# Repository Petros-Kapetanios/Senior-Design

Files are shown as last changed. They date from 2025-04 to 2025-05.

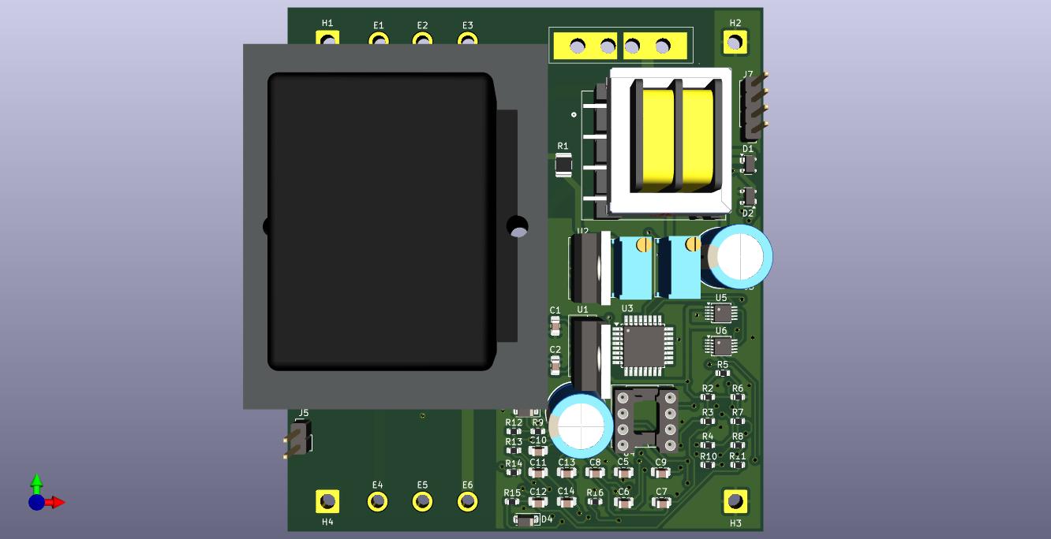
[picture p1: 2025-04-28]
Final_Board-v3C/Final_Board-v3C.jpg

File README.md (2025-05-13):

# Senior‑Design

Zip files of my Gerber files for each PCB I created for my watt‑meter project.

## Order of Creation

1. **Capacitor Test Board**
2. **Current Transformer Test Board**
3. **Voltage Transformer Test Board**
4. **Low Pass‑V1**
5. **Low Pass‑V2**
6. **Final_Board‑Analog‑v1**
7. **Final_Board‑Analog‑v2**
8. **Final_Board‑Analog‑v3**
9. **Final_Board‑v1**
10. **Final_Board‑v2**
11. **Final_Board‑v3‑Triple‑Transformer**
12. **Final_Board‑v3B**
13. **Final_Board‑v3B‑Mark’s Copy**
14. **Final_Board‑v3C**
15. **Final_Board‑v3D**

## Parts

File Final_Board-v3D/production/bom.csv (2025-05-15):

Designator | Footprint | Quantity | Value | LCSC Part #
C1, C4 | CP_Radial_D10.0mm_P5.00mm | 2 | 100 uF
C10, C11, C12, C9 | 0805 | 4 | 1.5 uF
C13, C8 | 0805 | 2 | 10 nF
C14 | 0805 | 1 | 22 nF
C2, C3, C5, C6 | 0805 | 4 | 1 uF
C7 | 0805 | 1 | 20 nF
D1, D2 | SOT-143 | 2 | BAS3007
D3, D4 | D_SOD-123 | 2 | D_Zener
E1, E2, E3, E4, E5, E6 | MountingHole_2.2mm_M2_ISO7380_Pad_TopBottom | 6 | TestPoint_Small
F1 | Fuseholder_Keystone_3555-2 | 1 | Fuse
H1, H2, H3, H4 | SolderWire-2sqmm_1x01_D2mm_OD3.9mm | 4 | Hole
J1, J4 | PinHeader_1x02_P2.54mm_Vertical | 2 | Conn_01x02_Pin
J1-2 | PinHeader_2x03_P2.54mm_Vertical | 1 | Conn_02x03_Odd_Even
J10, J8 | PinHeader_1x01_P2.54mm_Vertical | 2 | Conn_01x01_Pin
J5 | PinHeader_1x04_P2.54mm_Vertical | 1 | Conn_01x04_Pin
J6, J7 | PinSocket_1x02_P2.54mm_Vertical | 2 | Conn_01x02_Socket
J9 | PinSocket_1x04_P2.54mm_Vertical | 1 | Conn_01x04_Socket
R1 | 1210 | 1 | 240 K
R10 | 0603 | 1 | 1 K
R11, R13, R14, R17, R2, R3, R5, R7, R8 | 0603 | 9 | 10 K
R12, R6 | 0603 | 2 | 51.1 K
R15 | 0603 | 1 | 30
R16, R4 | 0603 | 2 | 20 K
R9 | 0603 | 1 | 3 K
RV1 | Potentiometer_Bourns_3296W_Vertical | 1 | 10K Pot
RV2 | Potentiometer_Bourns_3296W_Vertical | 1 | 10 K Pot
T1 | XFMR_VPP12-800 | 1 | VPP12-800
T2 | XFMR_CSE185L | 1 | CSE185L
U1 | TO-220-3_Vertical | 1 | 12 V Regulator
U2 | TO-220-3_Vertical | 1 | 5 V Regulator
U3 | TQFP-32_7x7mm_P0.8mm | 1 | ATmega328PB-A
U4 | DIP-8_W7.62mm_Socket | 1 | LM358
U5, U6 | TSSOP-10_3x3mm_P0.5mm | 2 | ADS1115IDGS

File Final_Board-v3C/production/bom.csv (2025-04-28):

Designator | Footprint | Quantity | Value | LCSC Part #
C1, C2, C5, C6 | 0805 | 4 | 1 uF
C10, C11, C12, C9 | 0805 | 4 | 1.5 uF
C13 | 0805 | 1 | 22 nF
C14, C8 | 0805 | 2 | 10 nF
C3, C4 | CP_Radial_D10.0mm_P5.00mm | 2 | 100 uF
C7 | 0805 | 1 | 20 nF
D1, D2 | SOT-143 | 2 | BAS3007
D3, D4 | D_SOD-123 | 2 | D_Zener
E1, E2, E3, E4, E5, E6 | MountingHole_2.2mm_M2_ISO7380_Pad_TopBottom | 6 | TestPoint_Small
F1 | Fuseholder_Keystone_3555-2 | 1 | Fuse
H1, H2, H3, H4 | SolderWire-2sqmm_1x01_D2mm_OD3.9mm | 4 | Hole
J5 | PinHeader_1x02_P2.54mm_Vertical | 1 | Conn_01x02_Pin
J7 | PinHeader_1x04_P2.54mm_Vertical | 1 | Conn_01x04_Pin
R1 | 1210 | 1 | 240 K
R10, R12, R13, R16, R2, R4, R6, R7 | 0603 | 8 | 10 K
R11, R5 | 0603 | 2 | 51.1 K
R14 | 0603 | 1 | 30
R15, R3 | 0603 | 2 | 20 K
R8 | 0603 | 1 | 3 K
R9 | 0603 | 1 | 1 K
RV1 | Potentiometer_Bourns_3296W_Vertical | 1 | 10K Pot
RV2 | Potentiometer_Bourns_3296W_Vertical | 1 | 10 K Pot
T1 | XFMR_VPP12-800 | 1 | VPP12-800
T2 | XFMR_CSE185L | 1 | CSE185L
U1 | TO-220-3_Vertical | 1 | 12 V Regulator
U2 | TO-220-3_Vertical | 1 | 5 V Regulator
U3 | TQFP-32_7x7mm_P0.8mm | 1 | ATmega328PB-A
U4 | DIP-8_W7.62mm_Socket | 1 | LM358
U5, U6 | TSSOP-10_3x3mm_P0.5mm | 2 | ADS1115IDGS

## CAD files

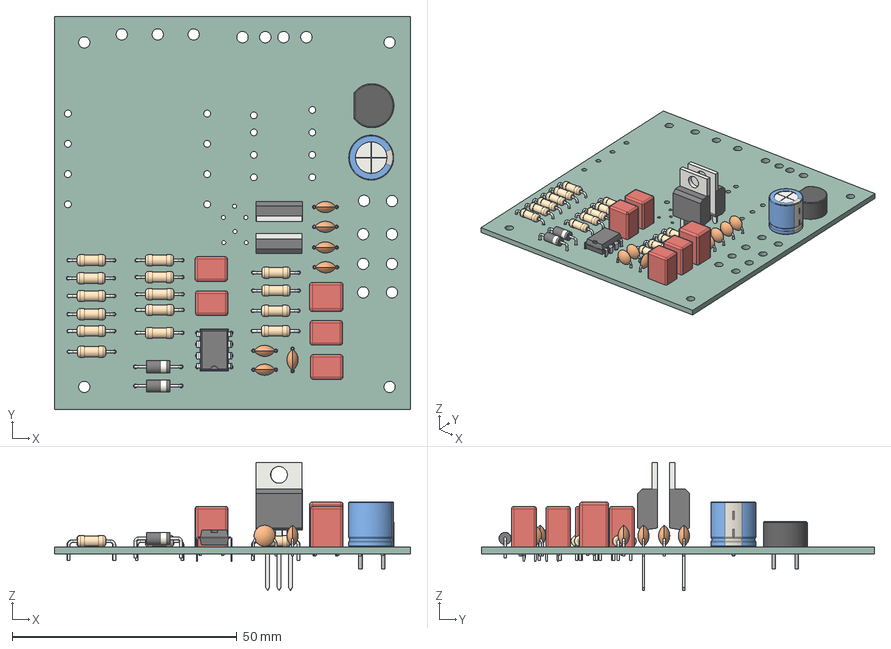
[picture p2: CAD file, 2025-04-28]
Final_Board-v3C/Final_Board-v3B.step
79.3 x 87.5 x 28.5 mm
R_Axial_DIN0207_L63mm_D25mm_P1016mm_Horizontal x 15
C_Disc_D47mm_W25mm_P500mm x 7
DIP-8_W7.62mm
C_Rect_L72mm_W55mm_P500mm_FKS2_FKP2_MKS2_MKP2 x 4
D_A-405_P10.16mm_Horizontal x 2
Diode_Bridge_Round_D9.8mm
TO-220-3_Vertical x 2
C_Rect_L75mm_W65mm_P500mm
CP_Radial_D100mm_P500mm
Final_Board-Analog-v2_PCB

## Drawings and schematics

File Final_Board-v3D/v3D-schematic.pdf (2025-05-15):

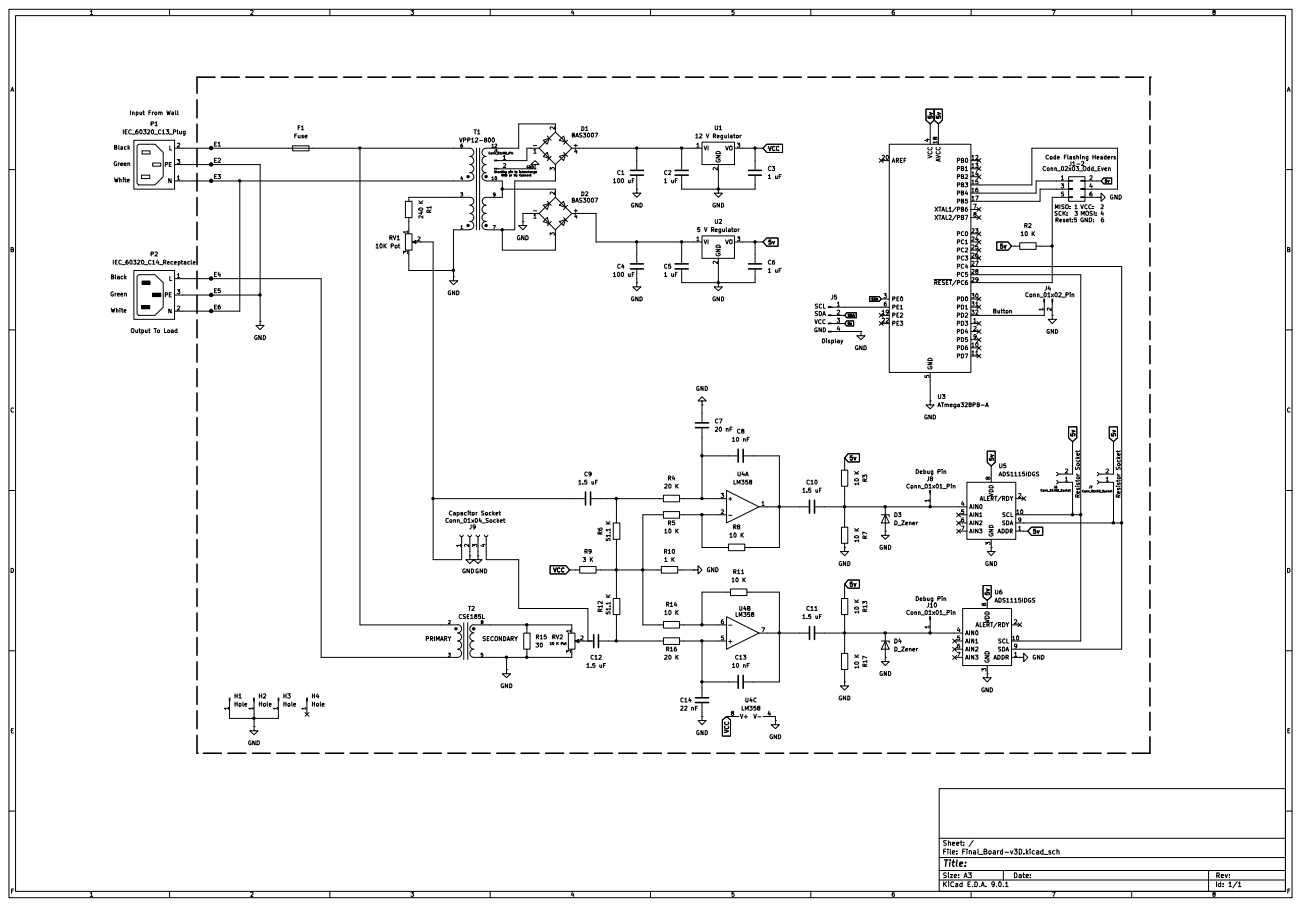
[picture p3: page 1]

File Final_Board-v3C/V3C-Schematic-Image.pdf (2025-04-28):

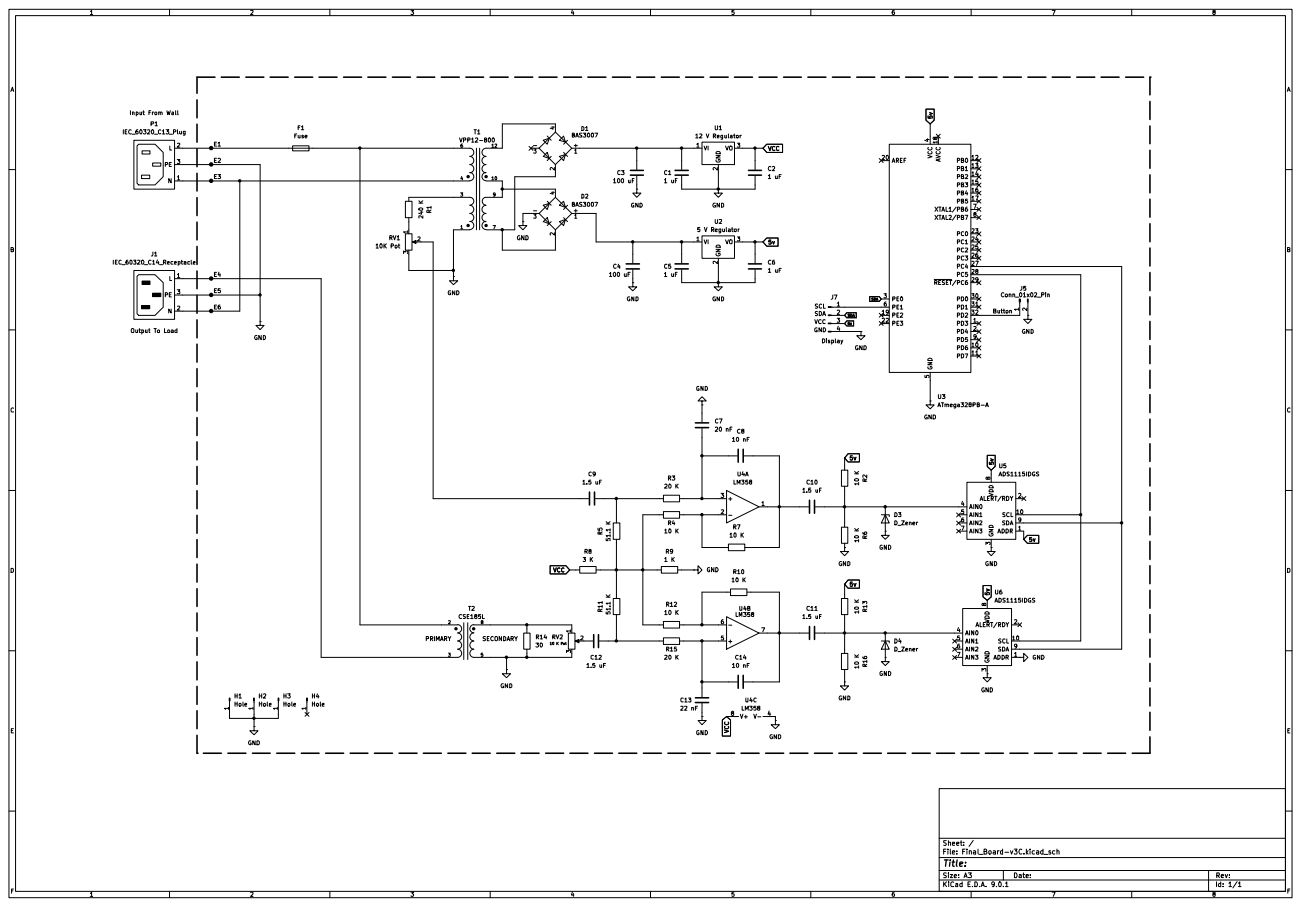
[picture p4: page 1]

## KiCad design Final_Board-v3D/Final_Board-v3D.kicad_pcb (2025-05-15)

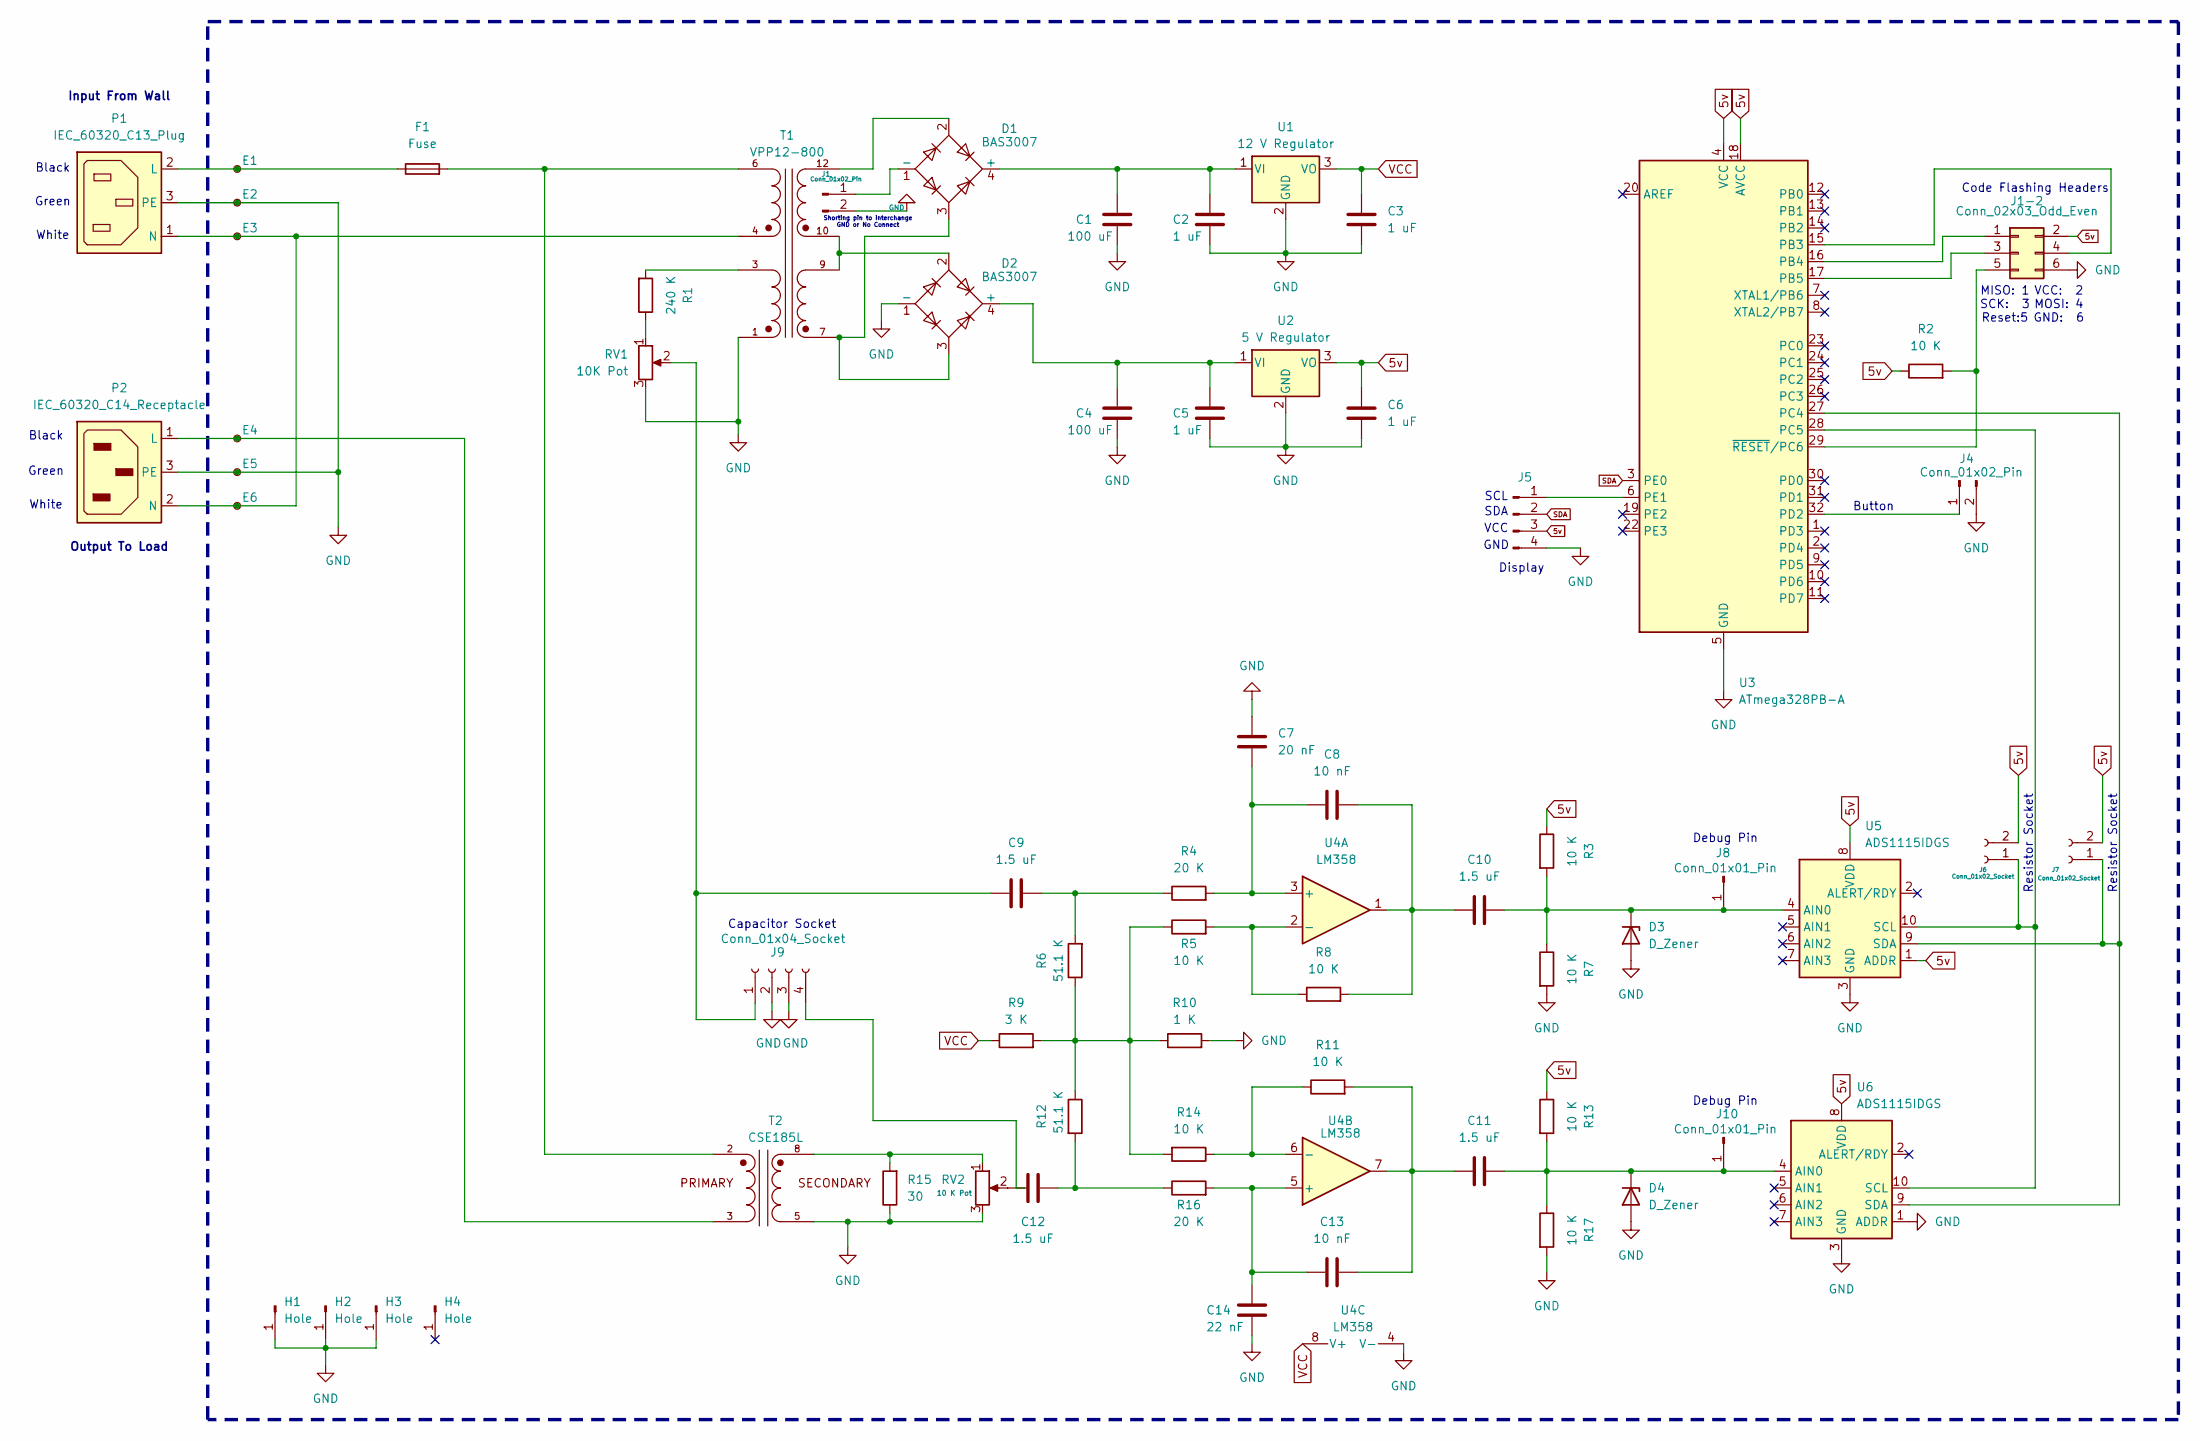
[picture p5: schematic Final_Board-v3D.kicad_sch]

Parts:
C1, C4: 100 uF; CP_Radial_D10.0mm_P5.00mm
C2, C3, C5, C6: 1 uF; C_0805_2012Metric_Pad1.18x1.45mm_HandSolder
C7: 20 nF; C_0805_2012Metric_Pad1.18x1.45mm_HandSolder
C8, C13: 10 nF; C_0805_2012Metric_Pad1.18x1.45mm_HandSolder
C9, C10, C11, C12: 1.5 uF; C_0805_2012Metric_Pad1.18x1.45mm_HandSolder
C14: 22 nF; C_0805_2012Metric_Pad1.18x1.45mm_HandSolder
D1, D2: BAS3007; SOT-143
D3, D4: D_Zener; D_SOD-123
E1, E2, E3, E4, E5, E6: TestPoint_Small; MountingHole_2.2mm_M2_ISO7380_Pad_TopBottom
F1: Fuse; Fuseholder_Keystone_3555-2
H1, H2, H3, H4: Hole; SolderWire-2sqmm_1x01_D2mm_OD3.9mm
J1, J4: Conn_01x02_Pin; PinHeader_1x02_P2.54mm_Vertical
J1-2: Conn_02x03_Odd_Even; PinHeader_2x03_P2.54mm_Vertical
J5: Conn_01x04_Pin; PinHeader_1x04_P2.54mm_Vertical
J6, J7: Conn_01x02_Socket; PinSocket_1x02_P2.54mm_Vertical
J8, J10: Conn_01x01_Pin; PinHeader_1x01_P2.54mm_Vertical
J9: Conn_01x04_Socket; PinSocket_1x04_P2.54mm_Vertical
P1: IEC_60320_C13_Plug
P2: IEC_60320_C14_Receptacle
R1: 240 K; R_1210_3225Metric
R2, R3, R5, R7, R8, R11, R13, R14, R17: 10 K; R_0603_1608Metric
R4, R16: 20 K; R_0603_1608Metric
R6, R12: 51.1 K; R_0603_1608Metric
R9: 3 K; R_0603_1608Metric
R10: 1 K; R_0603_1608Metric
R15: 30; R_0603_1608Metric
RV1: 10K Pot; Potentiometer_Bourns_3296W_Vertical
RV2: 10 K Pot; Potentiometer_Bourns_3296W_Vertical
T1: VPP12-800; XFMR_VPP12-800
T2: CSE185L; XFMR_CSE185L; PARTREV N/A
U1: 12 V Regulator; TO-220-3_Vertical
U2: 5 V Regulator; TO-220-3_Vertical
U3: ATmega328PB-A; TQFP-32_7x7mm_P0.8mm
U4: LM358; DIP-8_W7.62mm_Socket
U5, U6: ADS1115IDGS; TSSOP-10_3x3mm_P0.5mm

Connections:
5v: C6.1, J1-2.2, J5.3, J6.2, J7.2, R2.1, R3.1, R13.1, U2.3 (VO), U3.4 (VCC), U3.18 (AVCC), U5.1 (ADDR), U5.8 (VDD), U6.8 (VDD)
GND: C1.2, C2.2, C3.2, C4.2, C5.2, C6.2, C7.2, C14.1, D2.1 (-), D3.2 (A), D4.2 (A), E2.1, E5.1, H1.1, H2.1, H3.1, J1.2, J1-2.6, J4.2, J5.4, J9.2, J9.3, P1.3 (PE), P2.3 (PE), R7.2, R10.2, R15.1, R17.2, RV1.3, RV2.3, T1.1, T2.5, U1.2 (GND), U2.2 (GND), U3.5 (GND), U3.21 (GND), U4.4 (V-), U5.3 (GND), U6.1 (ADDR), U6.3 (GND)
unnamed: C9.2, R4.1, R6.2
unnamed: C8.2, C10.1, R8.2, U4.1
unnamed: C11.1, C13.2, R11.2, U4.7
unnamed: C12.1, RV2.2
unnamed: C12.2, R12.2, R16.1
unnamed: C1.1, C2.1, D1.4 (+), U1.1 (VI)
unnamed: D1.1 (-), J1.1
unnamed: D1.2, T1.12
unnamed: D1.3, D2.3, T1.7
unnamed: C4.1, C5.1, D2.4 (+), U2.1 (VI)
unnamed: D2.2, T1.9, T1.10
unnamed: C10.2, D3.1 (K), J8.1, R3.2, R7.1, U5.4 (AIN0)
unnamed: C11.2, D4.1 (K), J10.1, R13.2, R17.1, U6.4 (AIN0)
unnamed: F1.2, T1.6, T2.2
unnamed: J1-2.1, U3.16 (PB4)
unnamed: J1-2.3, U3.17 (PB5)
unnamed: J1-2.4, U3.15 (PB3)
unnamed: J1-2.5, R2.2, U3.29 (~RESET/PC6)
unnamed: J4.1, U3.32 (PD2)
unnamed: J5.1, U3.6 (PE1)
unnamed: J6.1, U3.28 (PC5), U5.10 (SCL), U6.10 (SCL)
unnamed: J7.1, U3.27 (PC4), U5.9 (SDA), U6.9 (SDA)
unnamed: C9.1, J9.1, RV1.2
unnamed: E1.1, F1.1, P1.2 (L)
unnamed: E3.1, E6.1, P1.1 (N), P2.2 (N), T1.4
unnamed: E4.1, P2.1 (L), T2.3
unnamed: R1.1, RV1.1
unnamed: R1.2, T1.3
unnamed: R5.1, R6.1, R9.2, R10.1, R12.1, R14.2
unnamed: R15.2, RV2.1, T2.8
unnamed: C7.1, C8.1, R4.2, U4.3 (+)
unnamed: R5.2, R8.1, U4.2 (-)
unnamed: C13.1, C14.2, R16.2, U4.5 (+)
unnamed: R11.1, R14.1, U4.6 (-)
SDA: J5.2, U3.3 (PE0)
VCC: C3.1, R9.1, U1.3 (VO), U4.8 (V+)

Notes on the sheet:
Resistor Socket
Shorting pin to interchange GND or No Connect
Black
SDA
Debug Pin
Green
Button
Capacitor Socket
Code Flashing Headers
White
SCL
Input From Wall
VCC
GND
Display
VCC: 2 MOSI: 4 GND: 6
Output To Load
MISO: 1 SCK: 3 Reset:5

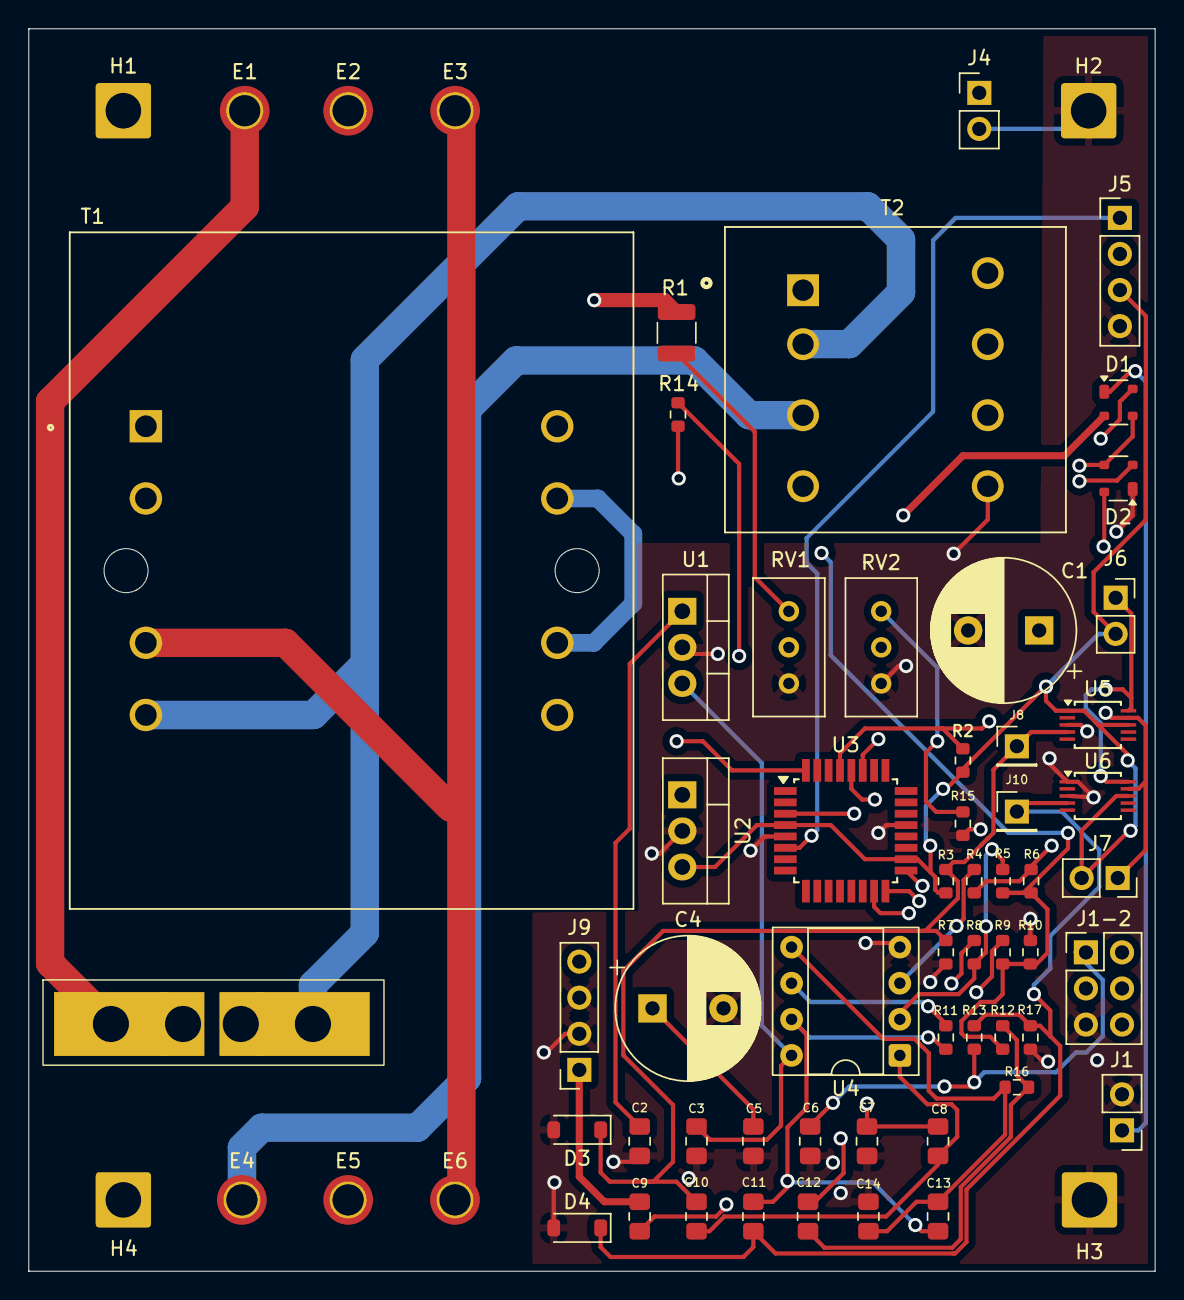
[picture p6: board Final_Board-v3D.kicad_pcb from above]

Board: 4 copper layers, 79.3 x 87.5 mm, 65 parts (0 on the bottom side), 38 nets.

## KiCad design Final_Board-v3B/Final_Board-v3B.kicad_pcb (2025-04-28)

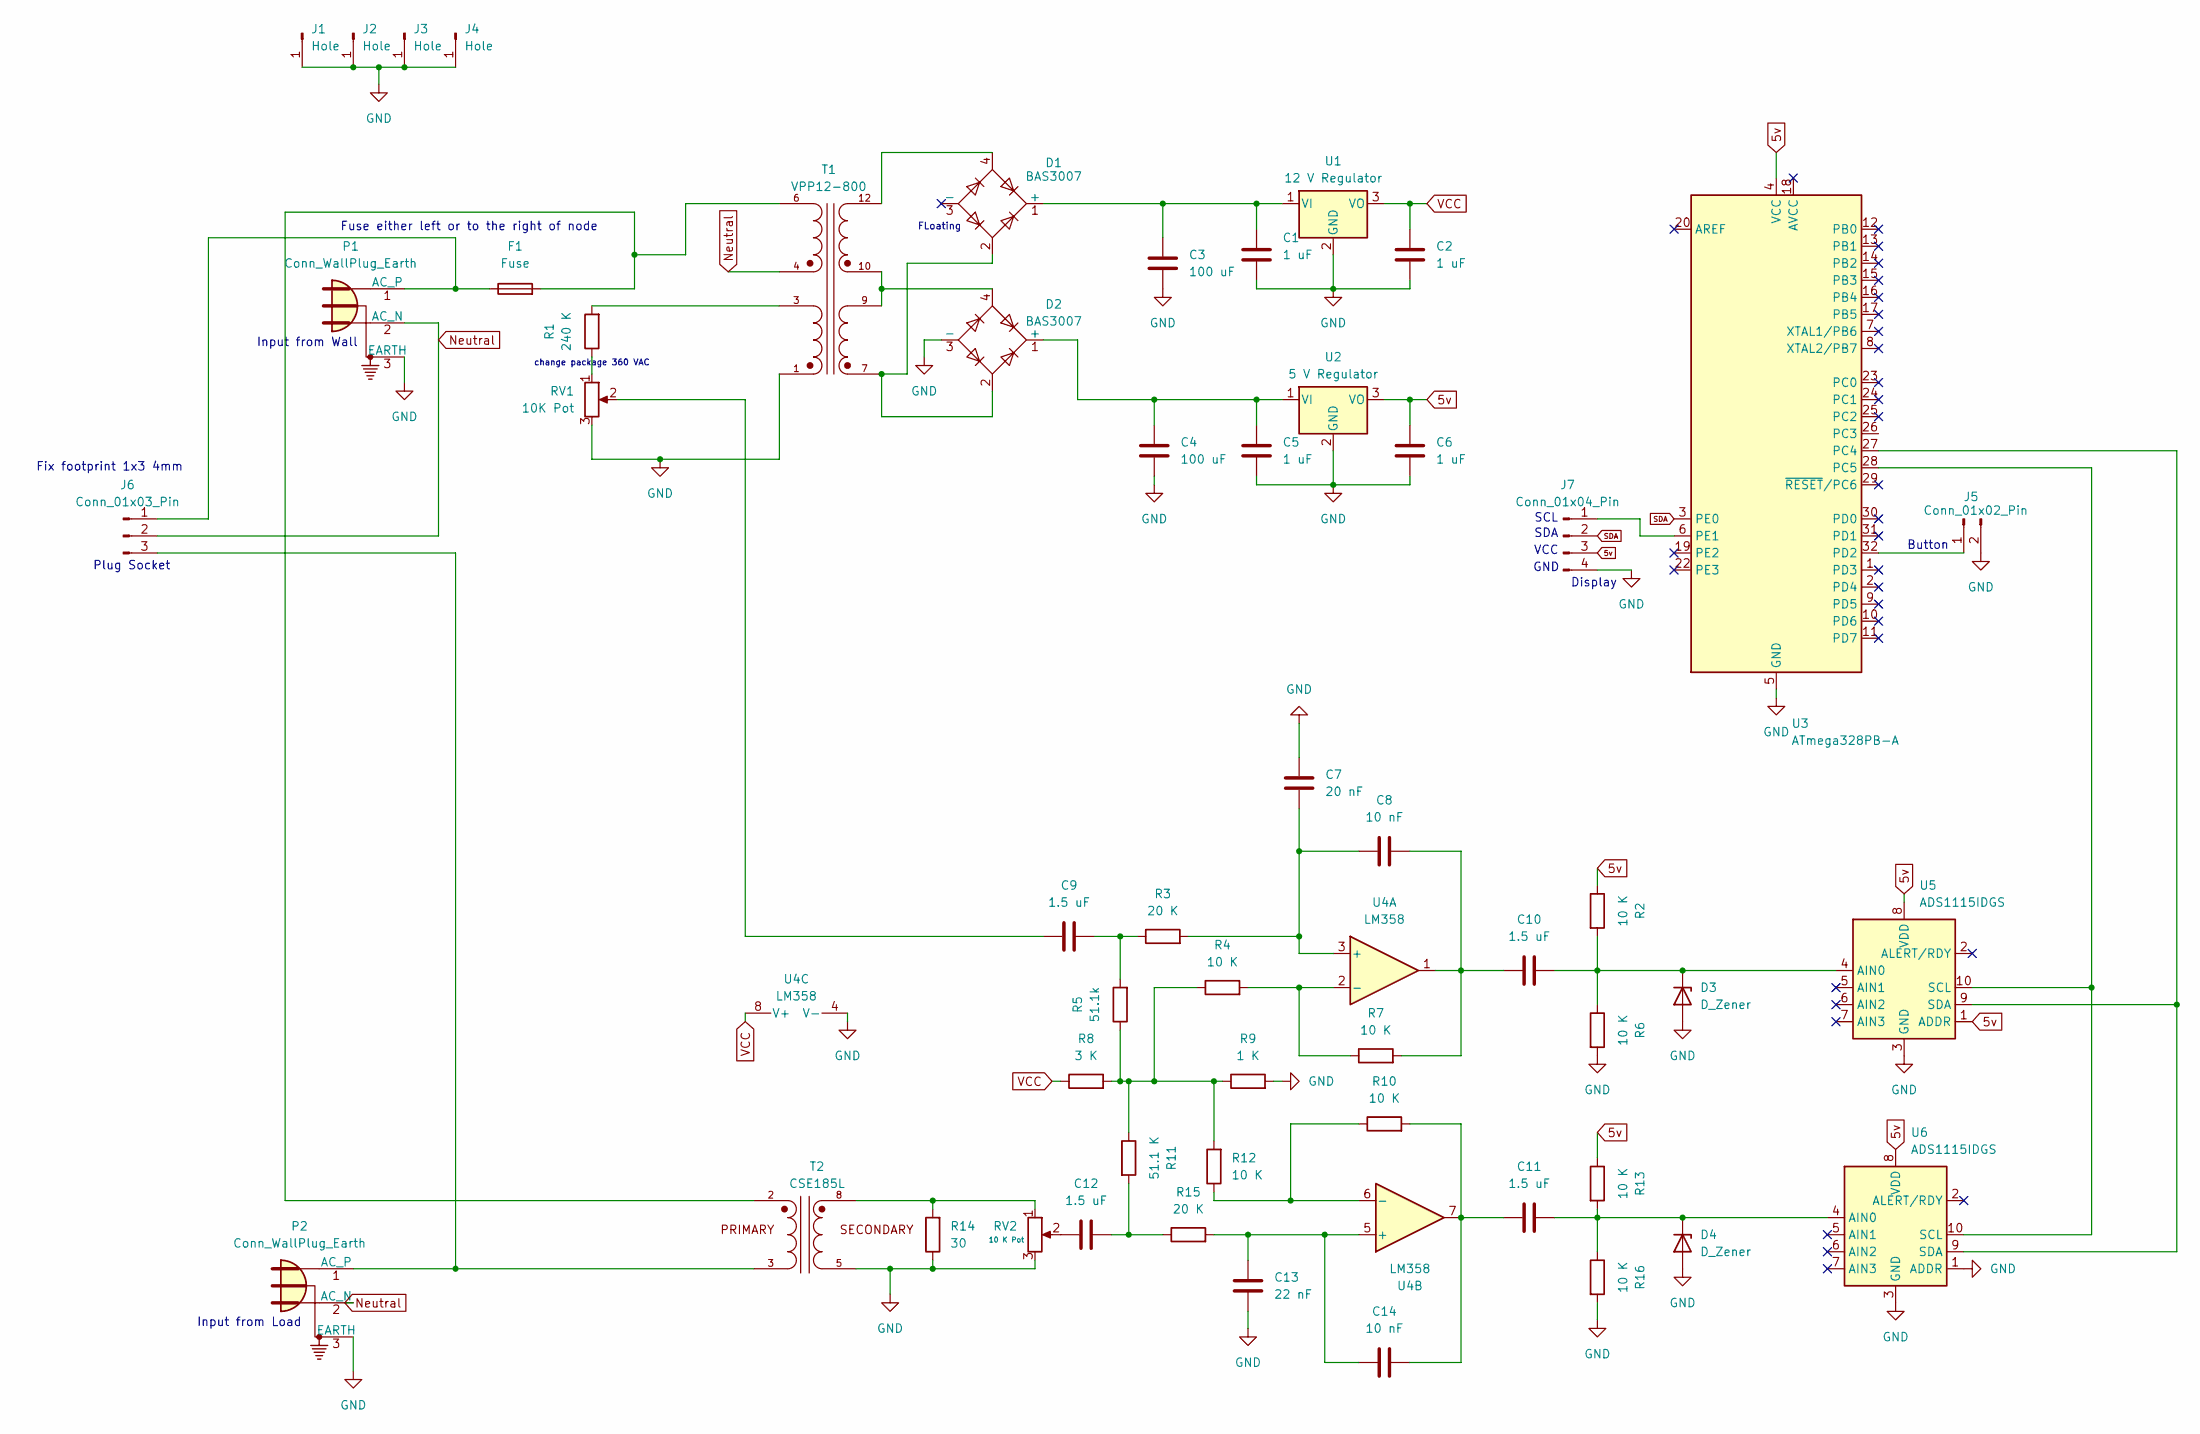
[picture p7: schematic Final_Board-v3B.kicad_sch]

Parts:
C1, C2, C5, C6: 1 uF; C_0805_2012Metric_Pad1.18x1.45mm_HandSolder
C3, C4: 100 uF; CP_Radial_D10.0mm_P5.00mm
C7: 20 nF; C_0805_2012Metric_Pad1.18x1.45mm_HandSolder
C8, C14: 10 nF; C_0805_2012Metric_Pad1.18x1.45mm_HandSolder
C9, C10, C11, C12: 1.5 uF; C_0805_2012Metric_Pad1.18x1.45mm_HandSolder
C13: 22 nF; C_0805_2012Metric_Pad1.18x1.45mm_HandSolder
D1, D2: BAS3007; SOT-143
D3, D4: D_Zener; D_SOD-123
F1: Fuse; Fuseholder_Keystone_3555-2
J1, J2, J3, J4: Hole; SolderWire-2sqmm_1x01_D2mm_OD3.9mm
J5: Conn_01x02_Pin; PinHeader_1x02_P2.00mm_Vertical
J6: Conn_01x03_Pin; SolderWire-0.15sqmm_1x03_P4mm_D0.5mm_OD1.5mm
J7: Conn_01x04_Pin; PinHeader_1x04_P2.00mm_Vertical
P1, P2: Conn_WallPlug_Earth
R1: 240 K; R_0603_1608Metric
R2, R4, R6, R7, R10, R12, R13, R16: 10 K; R_0603_1608Metric
R3, R15: 20 K; R_0603_1608Metric
R5: 51.1k; R_0603_1608Metric
R8: 3 K; R_0603_1608Metric
R9: 1 K; R_0603_1608Metric
R11: 51.1 K; R_0603_1608Metric
R14: 30; R_0603_1608Metric
RV1: 10K Pot; Potentiometer_Bourns_3296W_Vertical
RV2: 10 K Pot; Potentiometer_Bourns_3296W_Vertical
T1: VPP12-800; XFMR_VPP12-800
T2: CSE185L; XFMR_CSE185L; PARTREV N/A
U1: 12 V Regulator; TO-220-3_Vertical
U2: 5 V Regulator; TO-220-3_Vertical
U3: ATmega328PB-A; TQFP-32_7x7mm_P0.8mm
U4: LM358; DIP-8_W7.62mm
U5, U6: ADS1115IDGS; VSSOP-10_3x3mm_P0.5mm

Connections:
5v: C6.1, J7.3, R2.1, R13.1, U2.3 (VO), U3.4 (VCC), U5.1 (ADDR), U5.8 (VDD), U6.8 (VDD)
GND: C1.2, C2.2, C3.2, C4.2, C5.2, C6.2, C7.2, C13.1, D2.3 (-), D3.2 (A), D4.2 (A), J1.1, J2.1, J3.1, J4.1, J5.2, J7.4, P1.3 (EARTH), P2.3 (EARTH), R6.2, R9.2, R14.1, R16.2, RV1.3, RV2.3, T1.1, T2.5, U1.2 (GND), U2.2 (GND), U3.5 (GND), U3.21 (GND), U4.4 (V-), U5.3 (GND), U6.1 (ADDR), U6.3 (GND)
unnamed: C9.1, RV1.2
unnamed: C9.2, R3.1, R5.2
unnamed: C8.2, C10.1, R7.2, U4.1
unnamed: C11.1, C14.2, R10.2, U4.7
unnamed: C12.1, RV2.2
unnamed: C12.2, R11.2, R15.1
unnamed: C1.1, C3.1, D1.1 (+), U1.1 (VI)
unnamed: D1.2, D2.2, T1.7
unnamed: D1.4, T1.12
unnamed: C4.1, C5.1, D2.1 (+), U2.1 (VI)
unnamed: D2.4, T1.9, T1.10
unnamed: C10.2, D3.1 (K), R2.2, R6.1, U5.4 (AIN0)
unnamed: C11.2, D4.1 (K), R13.2, R16.1, U6.4 (AIN0)
unnamed: F1.2, T1.6, T2.2
unnamed: J5.1, U3.32 (PD2)
unnamed: F1.1, J6.1, P1.1 (AC_P)
unnamed: J6.3, P2.1 (AC_P), T2.3
unnamed: J7.1, U3.6 (PE1)
unnamed: R1.1, RV1.1
unnamed: R1.2, T1.3
unnamed: R4.1, R5.1, R8.2, R9.1, R11.1, R12.2
unnamed: R14.2, RV2.1, T2.8
unnamed: U3.27 (PC4), U5.9 (SDA), U6.9 (SDA)
unnamed: U3.28 (PC5), U5.10 (SCL), U6.10 (SCL)
unnamed: C7.1, C8.1, R3.2, U4.3 (+)
unnamed: R4.2, R7.1, U4.2 (-)
unnamed: C13.2, C14.1, R15.2, U4.5 (+)
unnamed: R10.1, R12.1, U4.6 (-)
Neutral: J6.2, P1.2 (AC_N), P2.2 (AC_N), T1.4
SDA: J7.2, U3.3 (PE0)
VCC: C2.1, R8.1, U1.3 (VO), U4.8 (V+)

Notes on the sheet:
SDA
change package 360 VAC
Plug Socket
Button
SCL
Fuse either left or to the right of node
Input from Wall
VCC
GND
FLoating
Fix footprint 1x3 4mm
Display
Input from Load

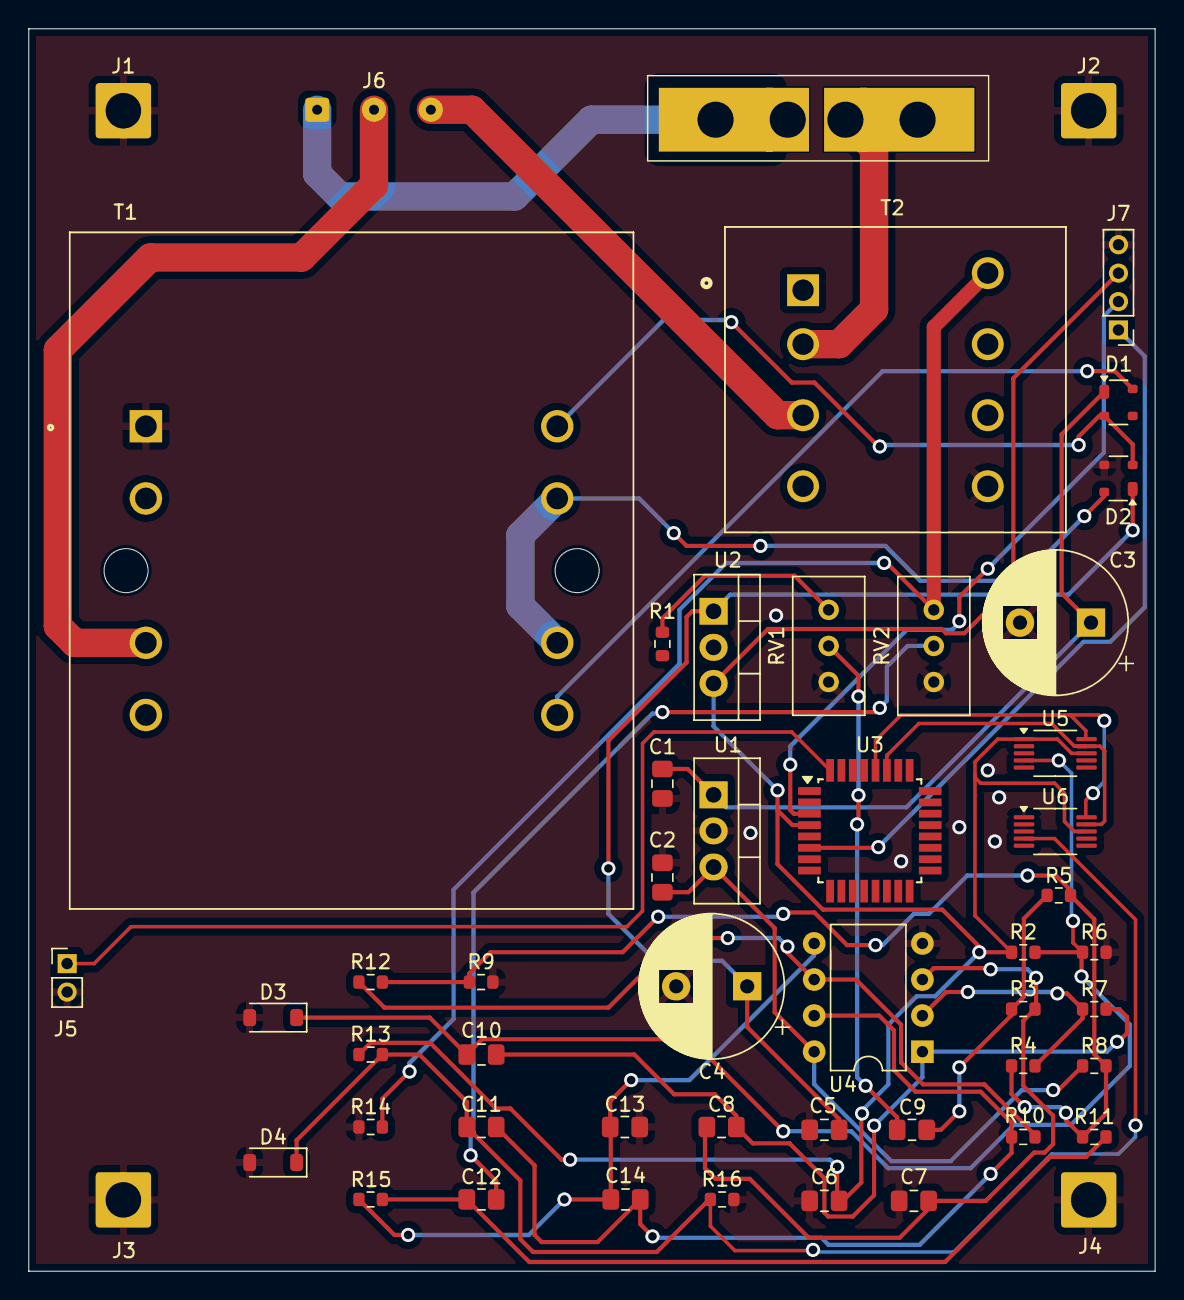
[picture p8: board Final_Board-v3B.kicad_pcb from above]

Board: 2 copper layers, 79.3 x 87.5 mm, 52 parts (0 on the bottom side), 33 nets.

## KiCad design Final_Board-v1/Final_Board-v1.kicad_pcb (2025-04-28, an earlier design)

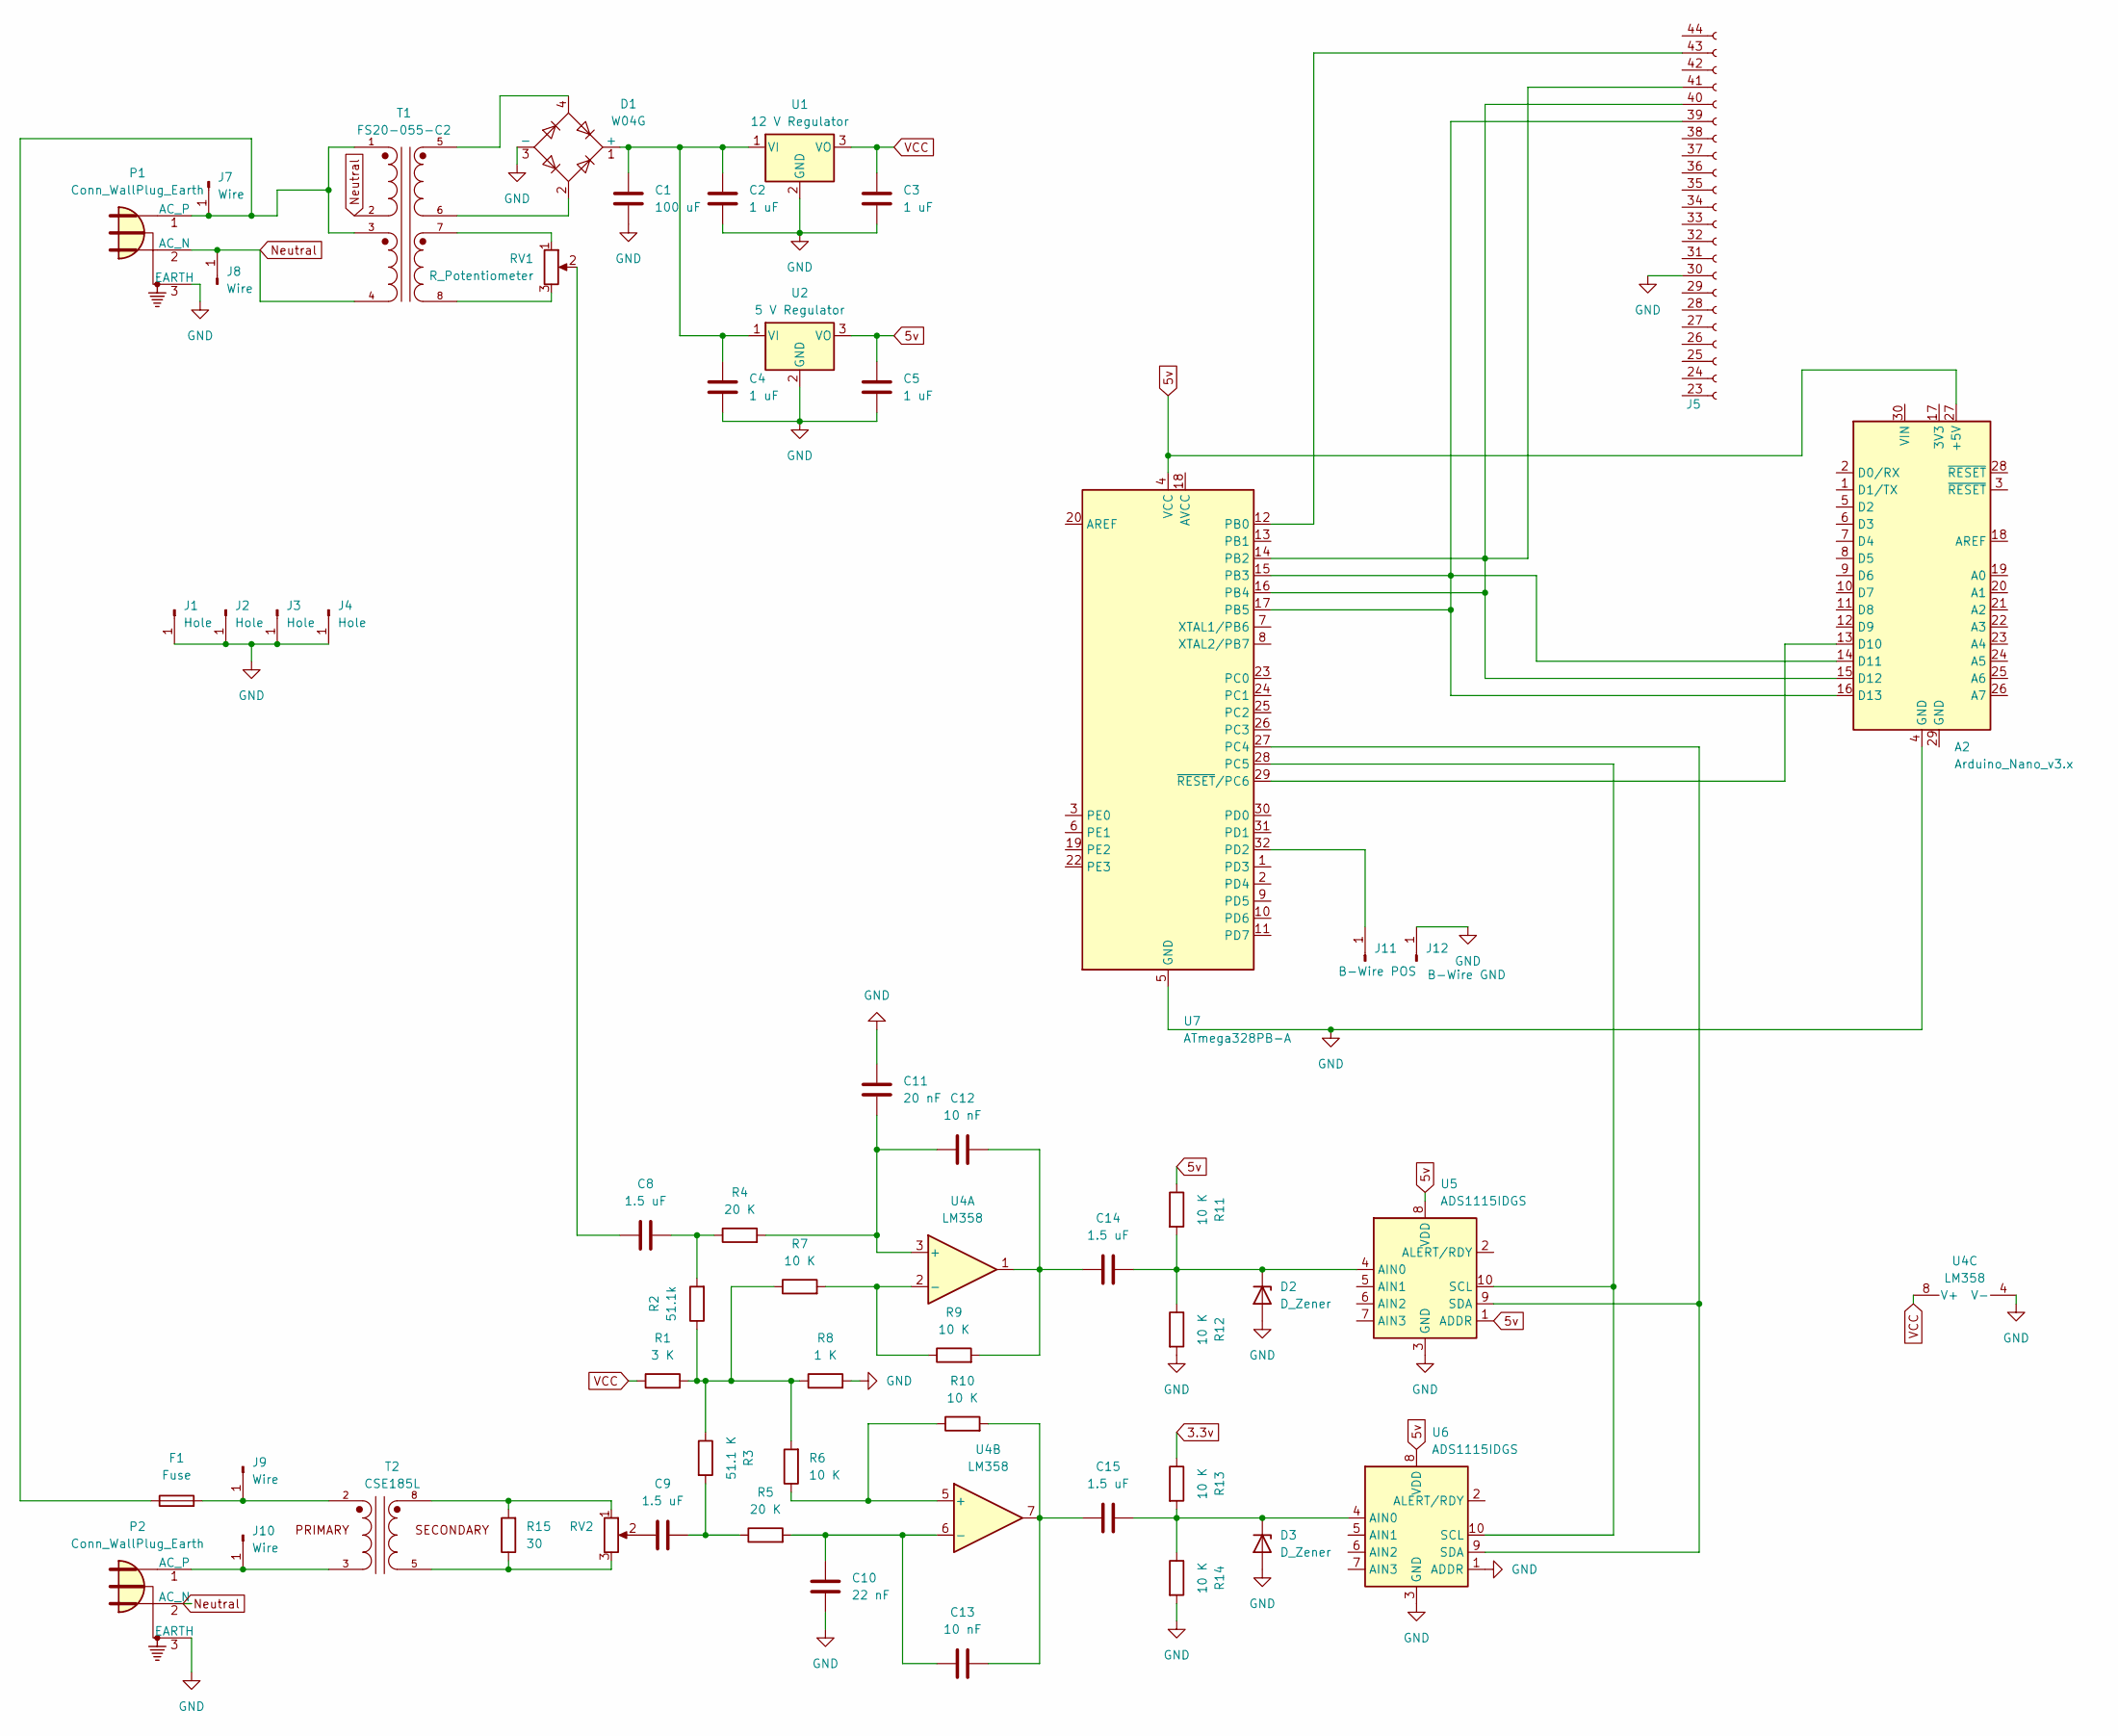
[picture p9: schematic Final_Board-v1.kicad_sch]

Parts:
A2: Arduino_Nano_v3.x; Arduino_Nano
C1: 100 uF; CP_Radial_D10.0mm_P5.00mm
C2, C3, C4, C5: 1 uF; C_Disc_D4.7mm_W2.5mm_P5.00mm
C8, C9, C14, C15: 1.5 uF; C_Rect_L7.2mm_W5.5mm_P5.00mm_FKS2_FKP2_MKS2_MKP2
C10: 22 nF; C_Disc_D4.7mm_W2.5mm_P5.00mm
C11: 20 nF; C_Rect_L7.5mm_W6.5mm_P5.00mm
C12, C13: 10 nF; C_Disc_D4.7mm_W2.5mm_P5.00mm
D1: W04G; Diode_Bridge_Round_D9.8mm
D2, D3: D_Zener; D_A-405_P10.16mm_Horizontal
F1: Fuse
J1, J2, J3, J4: Hole; SolderWire-2sqmm_1x01_D2mm_OD3.9mm
J5: Conn_01x22_Socket; PinSocket_1x22_P2.54mm_Vertical
J7, J8, J9, J10: Wire; SolderWire-2sqmm_1x01_D2mm_OD3.9mm
J11: B-Wire POS; SolderWire-2sqmm_1x01_D2mm_OD3.9mm
J12: B-Wire GND; SolderWire-2sqmm_1x01_D2mm_OD3.9mm
P1, P2: Conn_WallPlug_Earth
R1: 3 K; R_Axial_DIN0207_L6.3mm_D2.5mm_P10.16mm_Horizontal
R2: 51.1k; R_Axial_DIN0207_L6.3mm_D2.5mm_P10.16mm_Horizontal
R3: 51.1 K; R_Axial_DIN0207_L6.3mm_D2.5mm_P10.16mm_Horizontal
R4, R5: 20 K; R_Axial_DIN0207_L6.3mm_D2.5mm_P10.16mm_Horizontal
R6, R7, R9, R10, R14: 10 K; R_Axial_DIN0207_L6.3mm_D2.5mm_P10.16mm_Horizontal
R8: 1 K; R_1206_3216Metric
R11, R12, R13: 10 K; R_1206_3216Metric
R15: 30; R_Axial_DIN0207_L6.3mm_D2.5mm_P10.16mm_Horizontal
RV1, RV2: R_Potentiometer; Potentiometer_ACP_CA6-H2,5_Horizontal
T1: FS20-055-C2; XFMR_FS20-055-C2; PARTREV N/A
T2: CSE185L; XFMR_CSE185L; PARTREV N/A
U1: 12 V Regulator; TO-220-3_Vertical
U2: 5 V Regulator; TO-220-3_Vertical
U4: LM358; DIP-8_W7.62mm
U5, U6: ADS1115IDGS; TSSOP-10_3x3mm_P0.5mm
U7: ATmega328PB-A; TQFP-32_7x7mm_P0.8mm

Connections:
3.3v: R13.1; also elsewhere on the board
5v: A2.27 (+5V), C5.1, R11.1, U2.3 (VO), U5.1 (ADDR), U5.8 (VDD), U6.8 (VDD), U7.4 (VCC)
GND: A2.4 (GND), C1.2, C2.2, C3.2, C4.2, C5.2, C10.1, C11.2, D1.3 (-), D2.2 (A), D3.2 (A), J1.1, J2.1, J3.1, J4.1, J5.30, J12.1, P1.3 (EARTH), P2.3 (EARTH), R8.2, R12.2, R14.2, U1.2 (GND), U2.2 (GND), U4.4 (V-), U5.3 (GND), U6.1 (ADDR), U6.3 (GND), U7.5 (GND), U7.21 (GND); also elsewhere on the board
unnamed: A2.13 (D10), U7.29 (~RESET/PC6)
unnamed: A2.14 (D11), A2.16 (D13), J5.39, U7.15 (PB3), U7.17 (PB5)
unnamed: A2.15 (D12), J5.40, J5.41, U7.14 (PB2), U7.16 (PB4)
unnamed: C8.1, RV1.2
unnamed: C8.2, R2.2, R4.1
unnamed: C9.1, RV2.2
unnamed: C9.2, R3.2, R5.1
unnamed: C12.2, C14.1, R9.2, U4.1
unnamed: C13.2, C15.1, R10.2, U4.7
unnamed: C1.1, C2.1, C4.1, D1.1 (+), U1.1 (VI), U2.1 (VI)
unnamed: D1.2, T1.6
unnamed: D1.4, T1.5
unnamed: C14.2, D2.1 (K), R11.2, R12.1, U5.4 (AIN0)
unnamed: C15.2, D3.1 (K), R13.2, R14.1, U6.4 (AIN0)
unnamed: J5.43, U7.12 (PB0)
unnamed: F1.1, J7.1, P1.1 (AC_P), T1.1, T1.3
unnamed: F1.2, J9.1, T2.2
unnamed: J10.1, P2.1 (AC_P), T2.3
unnamed: J11.1, U7.32 (PD2)
unnamed: R1.2, R2.1, R3.1, R6.2, R7.1, R8.1
unnamed: R15.1, RV2.3, T2.5
unnamed: R15.2, RV2.1, T2.8
unnamed: RV1.1, T1.7
unnamed: RV1.3, T1.8
unnamed: C11.1, C12.1, R4.2, U4.3 (+)
unnamed: R7.2, R9.1, U4.2 (-)
unnamed: R6.1, R10.1, U4.5 (+)
unnamed: C10.2, C13.1, R5.2, U4.6 (-)
unnamed: U5.10 (SCL), U6.10 (SCL), U7.28 (PC5)
unnamed: U5.9 (SDA), U6.9 (SDA), U7.27 (PC4)
Neutral: J8.1, P1.2 (AC_N), P2.2 (AC_N), T1.2, T1.4
VCC: C3.1, R1.1, U1.3 (VO), U4.8 (V+)

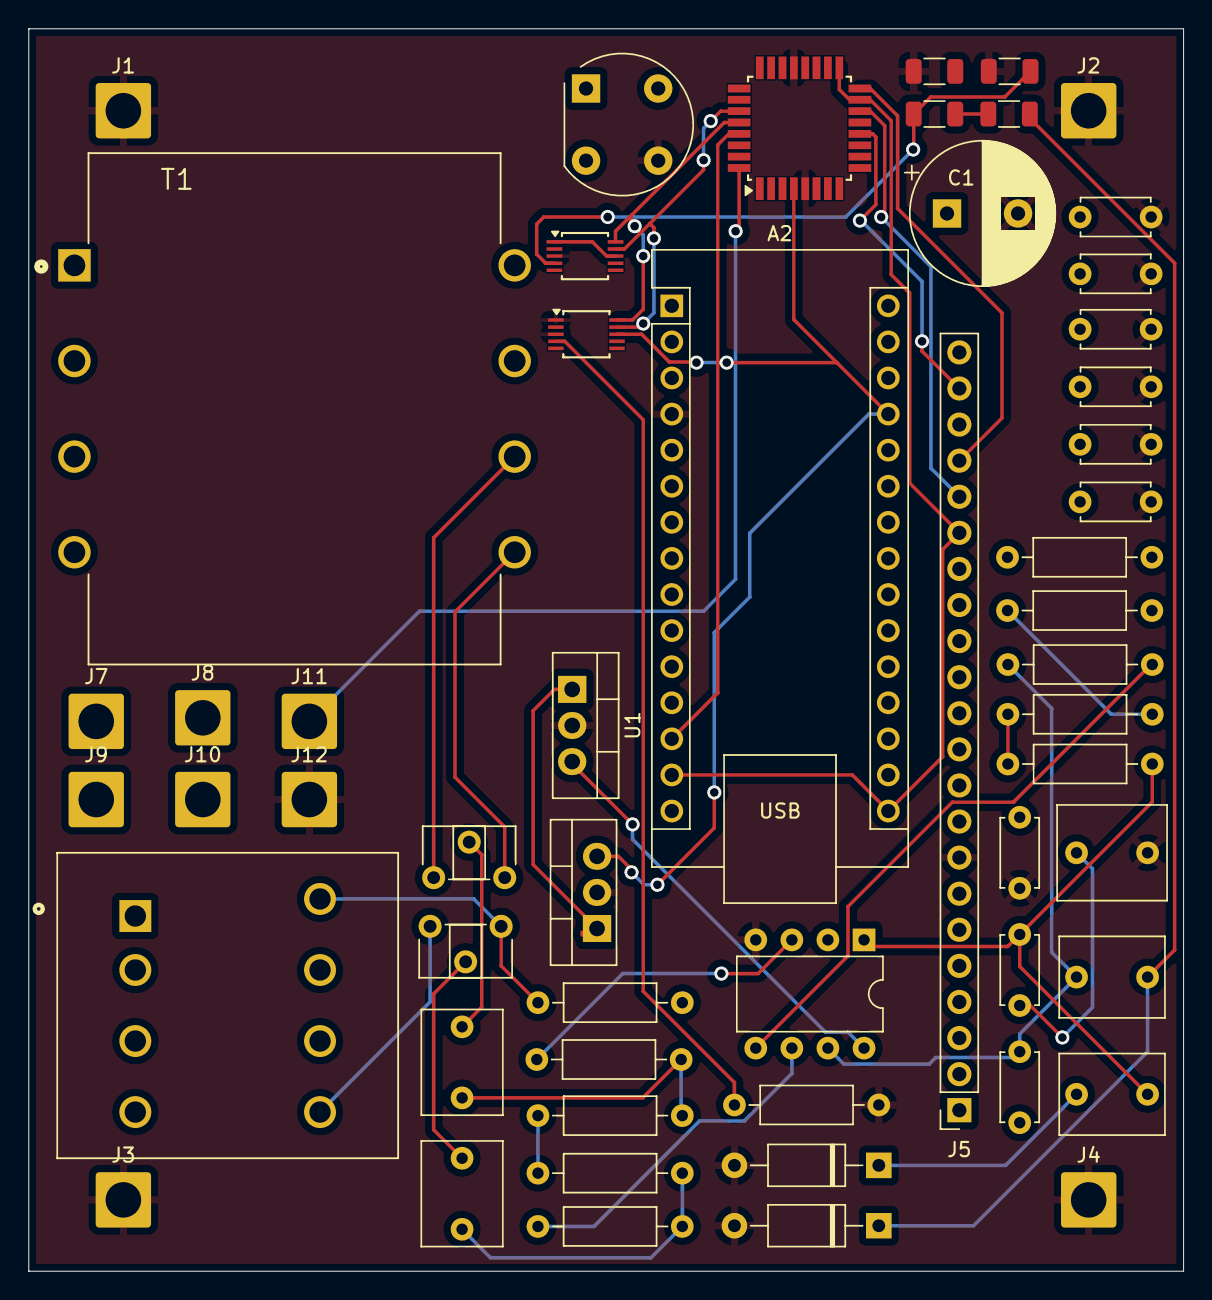
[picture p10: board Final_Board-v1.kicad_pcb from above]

Board: 2 copper layers, 81.3 x 87.5 mm, 55 parts (0 on the bottom side), 35 nets.

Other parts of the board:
C6, C7: 1 uF; C_Disc_D4.7mm_W2.5mm_P5.00mm

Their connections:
3.3v: C6.1, C7.1; also elsewhere on the board
GND: C6.2, C7.2; also elsewhere on the board

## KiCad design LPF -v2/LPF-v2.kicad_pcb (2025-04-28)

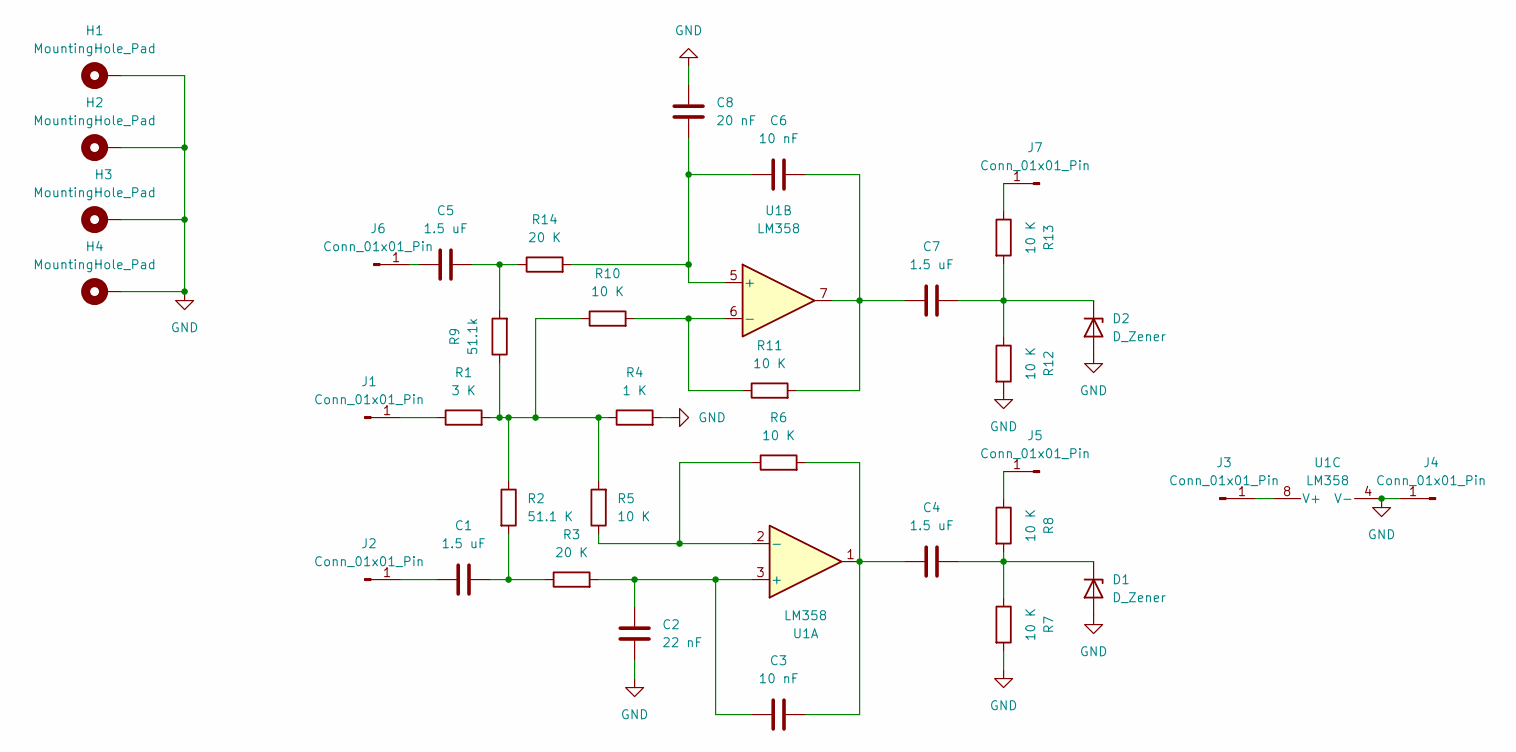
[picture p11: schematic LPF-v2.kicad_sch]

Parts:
C1, C4, C5, C7: 1.5 uF; C_Rect_L7.2mm_W5.5mm_P5.00mm_FKS2_FKP2_MKS2_MKP2
C2: 22 nF; C_Rect_L7.5mm_W6.5mm_P5.00mm
C3: 10 nF; C_Disc_D7.5mm_W5.0mm_P5.00mm
C6: 10 nF; C_Rect_L7.2mm_W5.5mm_P5.00mm_FKS2_FKP2_MKS2_MKP2
C8: 20 nF; C_Rect_L7.5mm_W6.5mm_P5.00mm
D1, D2: D_Zener; D_A-405_P10.16mm_Horizontal
H1, H2, H3, H4: MountingHole_Pad; MountingHole_3.2mm_M3_DIN965_Pad_TopBottom
J1, J2, J3, J4, J5, J6, J7: Conn_01x01_Pin; PinHeader_1x01_P2.54mm_Vertical
R1: 3 K; R_Axial_DIN0207_L6.3mm_D2.5mm_P10.16mm_Horizontal
R2: 51.1 K; R_Axial_DIN0207_L6.3mm_D2.5mm_P10.16mm_Horizontal
R3, R14: 20 K; R_Axial_DIN0207_L6.3mm_D2.5mm_P10.16mm_Horizontal
R4: 1 K; R_Axial_DIN0207_L6.3mm_D2.5mm_P10.16mm_Horizontal
R5, R6, R7, R8, R10, R11, R12, R13: 10 K; R_Axial_DIN0207_L6.3mm_D2.5mm_P10.16mm_Horizontal
R9: 51.1k; R_Axial_DIN0207_L6.3mm_D2.5mm_P10.16mm_Horizontal
U1: LM358; DIP-8_W7.62mm

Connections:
GND: C2.1, C8.2, D1.2 (A), D2.2 (A), H1.1, H2.1, H3.1, H4.1, J4.1, R4.2, R7.2, R12.2, U1.4 (V-)
unnamed: C1.2, R2.2, R3.1
unnamed: C3.2, C4.1, R6.2, U1.1
unnamed: C5.2, R9.2, R14.1
unnamed: C6.2, C7.1, R11.2, U1.7
unnamed: C4.2, D1.1 (K), R7.1, R8.2
unnamed: C7.2, D2.1 (K), R12.1, R13.2
unnamed: J1.1, R1.1
unnamed: C1.1, J2.1
unnamed: J3.1, U1.8 (V+)
unnamed: J5.1, R8.1
unnamed: C5.1, J6.1
unnamed: J7.1, R13.1
unnamed: R1.2, R2.1, R4.1, R5.2, R9.1, R10.1
unnamed: C2.2, C3.1, R3.2, U1.3 (+)
unnamed: R5.1, R6.1, U1.2 (-)
unnamed: C6.1, C8.1, R14.2, U1.5 (+)
unnamed: R10.2, R11.1, U1.6 (-)

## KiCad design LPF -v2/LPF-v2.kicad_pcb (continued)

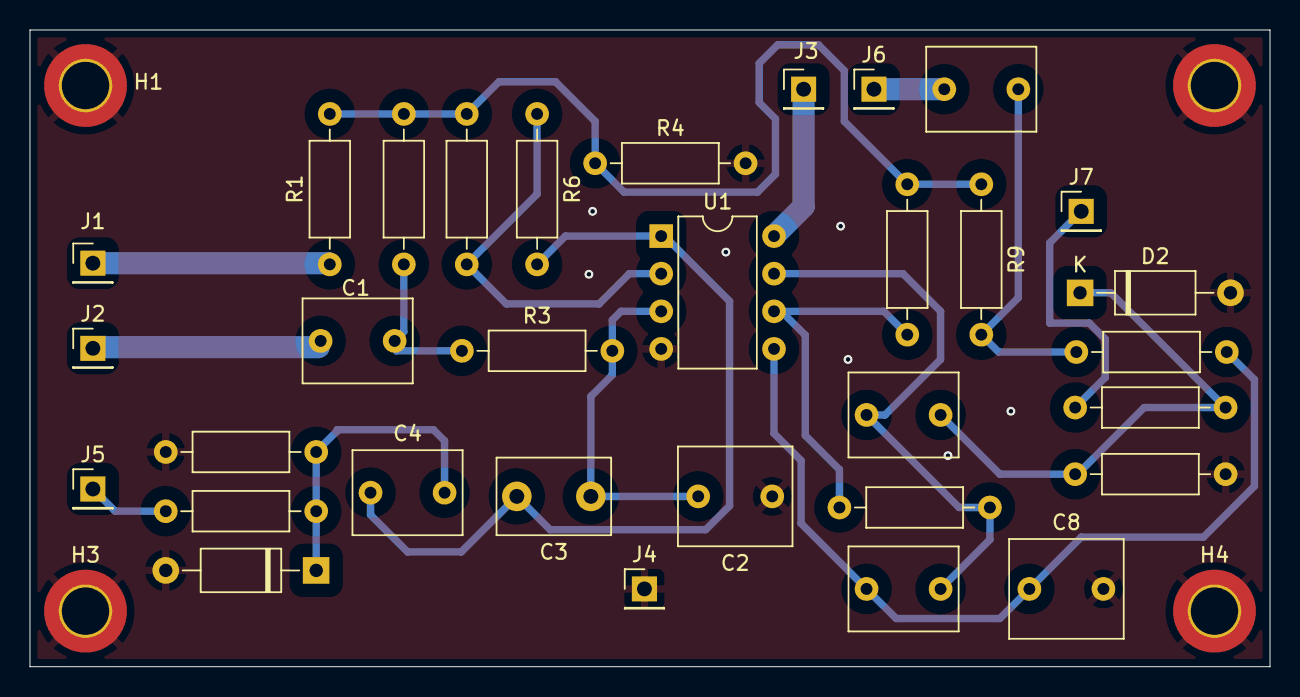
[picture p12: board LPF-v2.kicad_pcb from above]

Board: 2 copper layers, 83.8 x 43.0 mm, 36 parts (0 on the bottom side), 18 nets.

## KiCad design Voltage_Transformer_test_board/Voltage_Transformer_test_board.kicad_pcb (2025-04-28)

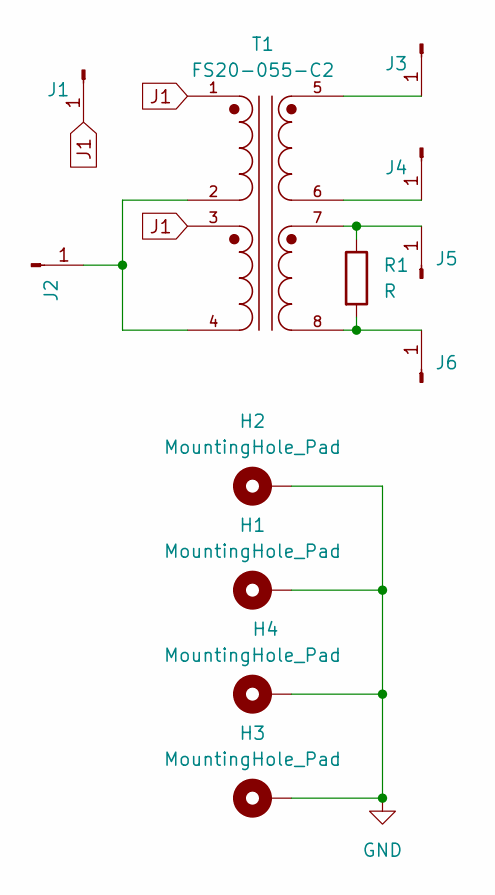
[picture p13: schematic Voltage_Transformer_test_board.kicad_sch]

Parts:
H1, H2, H3, H4: MountingHole_Pad; MountingHole_3.2mm_M3_DIN965_Pad_TopBottom
J1, J2, J3, J4, J5, J6: Conn_01x01_Pin; SolderWire-2sqmm_1x01_D2mm_OD3.9mm
R1: R; R_Axial_DIN0207_L6.3mm_D2.5mm_P10.16mm_Horizontal
T1: FS20-055-C2; XFMR_FS20-055-C2; PARTREV N/A

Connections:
GND: H1.1, H2.1, H3.1, H4.1
J1: J1.1, T1.1, T1.3
unnamed: J2.1, T1.2, T1.4
unnamed: J3.1, T1.5
unnamed: J4.1, T1.6
unnamed: J5.1, R1.1, T1.7
unnamed: J6.1, R1.2, T1.8

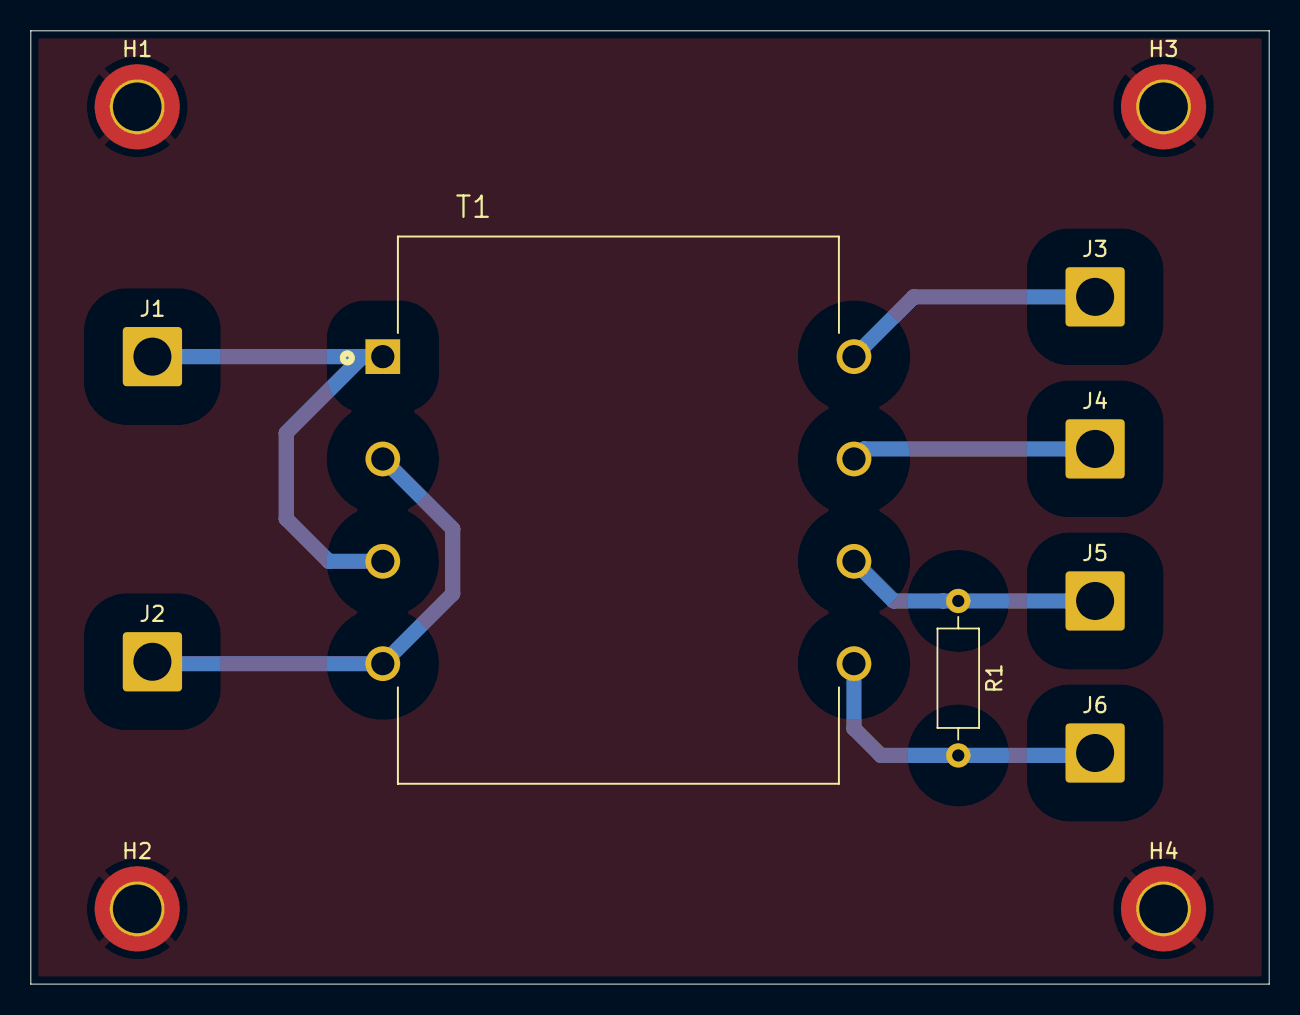
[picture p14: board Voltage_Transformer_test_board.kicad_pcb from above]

Board: 2 copper layers, 81.4 x 62.7 mm, 12 parts (0 on the bottom side), 7 nets.
